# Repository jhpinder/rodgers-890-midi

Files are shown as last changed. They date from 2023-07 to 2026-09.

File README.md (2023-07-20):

# Rodgers 890 Westminster MIDI Project

## Overview 

When installed and used correctly, this project:

- allows the 890 console to be used as a MIDI controller/receiver
- prevents the 890 from emitting any original analog sounds
- is non-destructive to the original analog tone generation
- gives the option to revert back to the original 890 analog tone generation

## Theory

The 890 reads in keyboards/pistons/stops using 4021 shift registers.
There are five data input chains:
- swell
- great
- pedal
- choir
- drawknobs/tablets

The 890 sets lamp outputs using 4094 shift registers into 2804 transistors.
There are six output chains:
- pipe chest
- swell/choir
- great
- pedal
- stops
- lamps

We will be using all the input chains since we are using almost every input, but only the sixth output for lamps since we are only driving lamps.

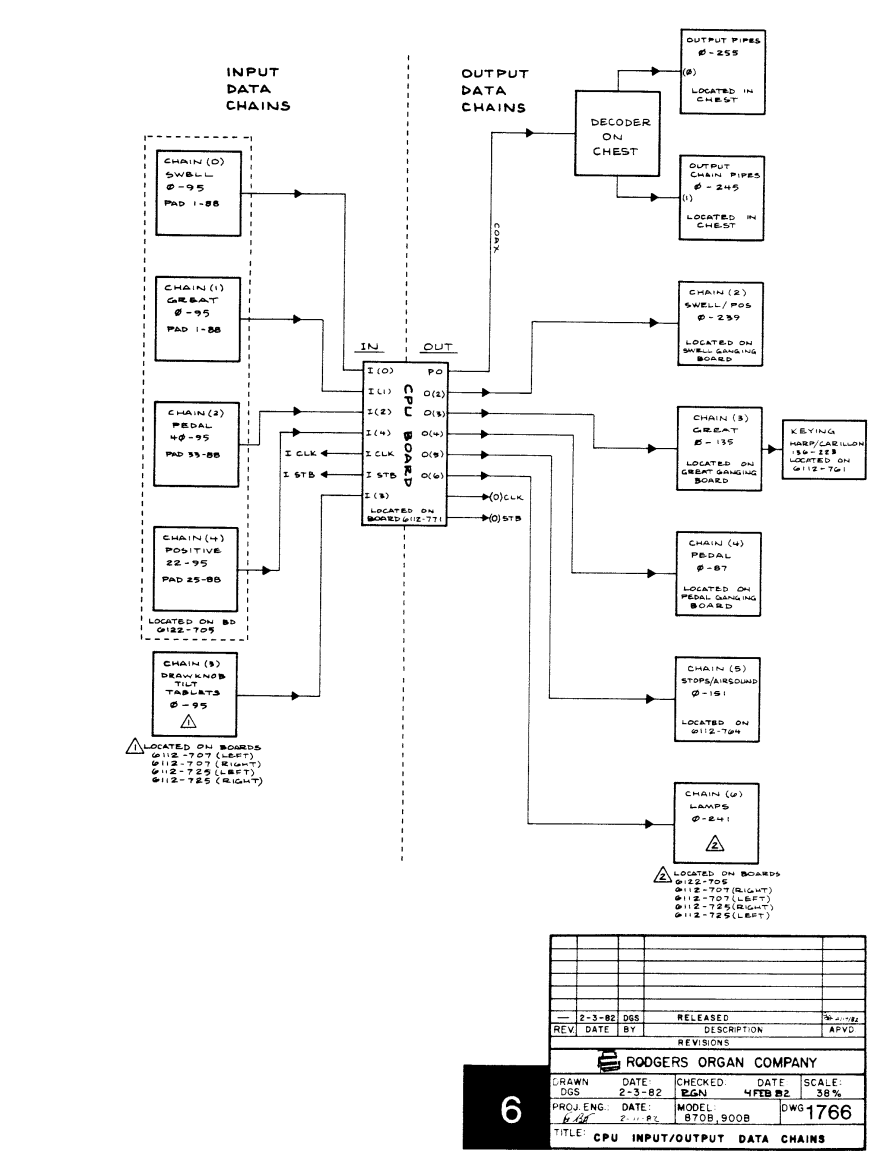
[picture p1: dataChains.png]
Data chains


---
### MIDI Latency

Every MIDI note command take approximately 1 millisecond to transmit.
We have over 90 lamps that can be changed at any time from the MIDI input.
This means if there are 50 lamp changes, it will take at least 50ms before the processor empties out the MIDI receive queue.
The acceptable time between note refreshing is 10ms.
If the organist is playing notes constantly and presses a piston that changes more than 10 lamps, there will theoretically be a delay before the next note refresh.

There are several solutions to this issue.

### *Solution 1: Hardware separation of keyboards and stops*

We can use one processor and MIDI port to process all the keyboards and their corresponding pistons and another processor and MIDI port to handle all the stops and lamps.
USB-MIDI interfaces sometimes feature multiple MIDI ports which are completely independent of each other.
This would allow one processor to dedicate its MIDI port to sending keyboard/piston note commands with no connection to the stops/lamps.
The other processor would be able to spend as much time as needed to receive MIDI notes and update lamps.

### *Solution 2 (**Current**): MIDI receive processing limits*

During each loop, we check if `MIDI.read()` is true (if there is an incoming message).
We continue to process MIDI messages in each loop until the incoming queue is empty.
However, if we receive more than 10 note commands at once, that breaks the limit of 10ms.
Before each time we check for an incoming message, we check to see if more than 10ms has elapsed since the last keyboard scan.
We do not update the lamps until the entire message queue has been emptied so as not to possibly create a ripple effect.
This complicates the code a little bit but allows the entire organ to run off of one MIDI port.
The logic for determining if more than the allowed amount of time has passed since the last keyboard read can be bypassed by connecting pin 3 to ground. For this to take effect, the arduino must be reset.

---
### Drawknobs and Tilt Tabs

Each drawknob and tilt tab has a lamp, an "on" contact, and an "off" contact.
When you turn the stop on, you pull the drawknob and release.
The lamp turns on and the drawknob moves back to its default center position.
The same goes for pushing the stop to turn it off.
The act of pushing or pulling a stop physically changes the state of the 2804 transistor and also changes the state of the corresponding 4021 shift register.
This means that there is a possibility of echoing a MIDI note on or note off command coming from the organ software.

To solve this issue, when receiving MIDI note commands, we `or` the "previous state" word with any reveiced MIDI note command. When scanning for changes on the next loop, those changes that are now read in do not trigger new MIDI note commands to be sent back to the organ software.

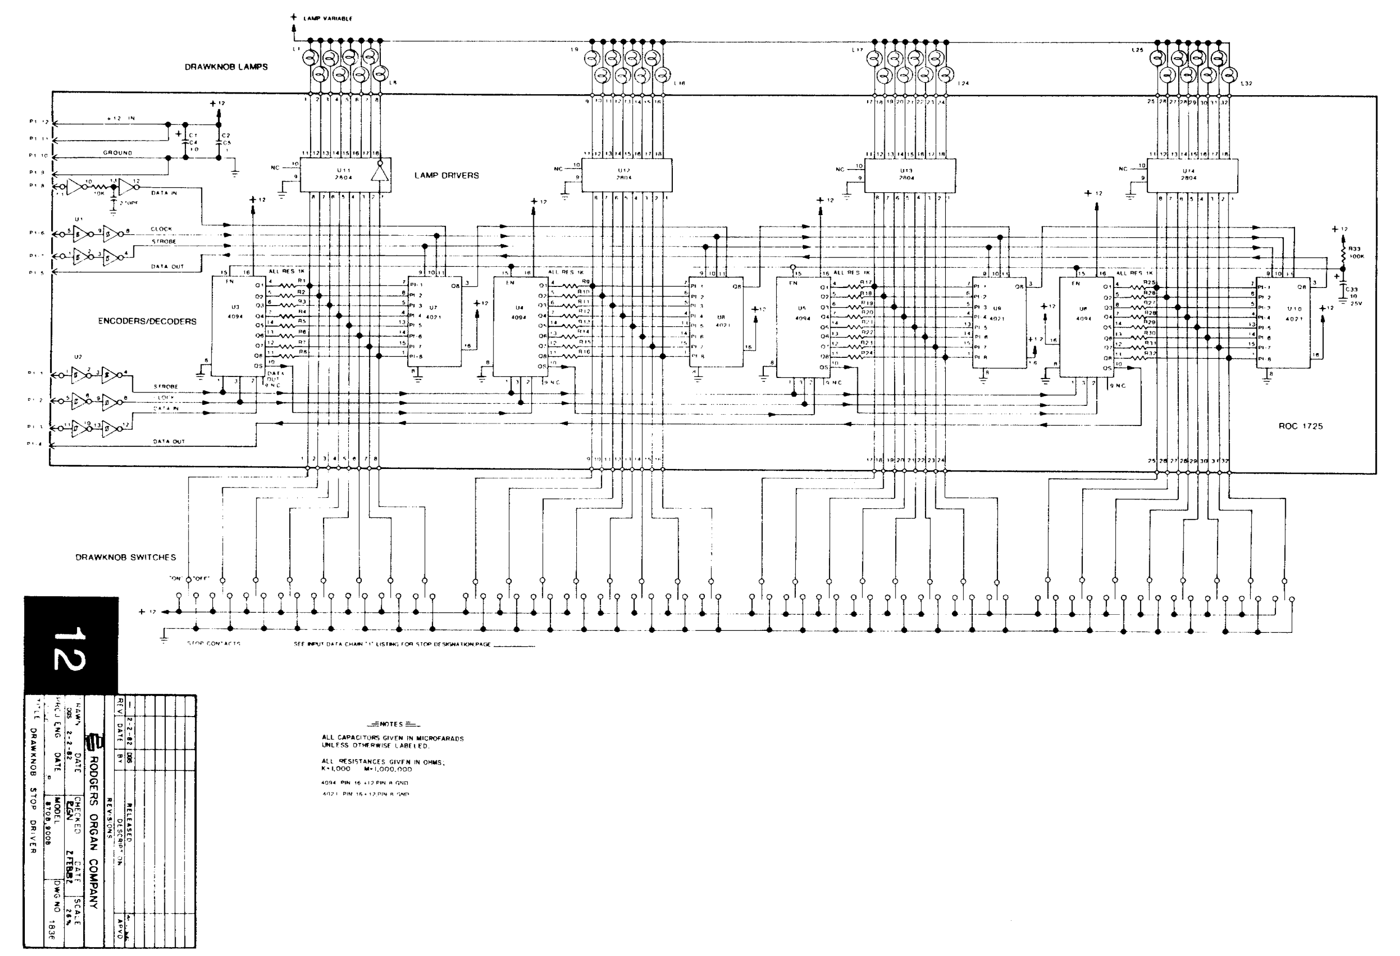
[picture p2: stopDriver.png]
Stop driver


---
### I/O Chain <-> MIDI

There are 5 input chains and one output chain that interface with MIDI. Four of the input chains contain a keyboard but they do not start at the 36th position, rather the 33rd for manuals and 65th for pedals.
If we output the raw chain position to MIDI, there will be a transposition required by the organ software.
Instead, we have opted to shift the positions of the input chain before we send out the MIDI note events.
This also means that the pistons associated with each keyboard are shifted as well.
To further complicate the matter, the lamps associated with each piston are not lined up 1:1 in an output chain with each input piston.
Instead, the piston lamps are added on to the end of the drawknob lamp output chain.

We have developed two functions that interface between the I/O chains and MIDI events.
The function `chainToMidi()` accepts the input chain number and bit address, and returns the corresponding MIDI channel and note number.
The function `midiToChain()` accepts a MIDI channel and note, and returns the corresponding output chain number and bit address.

This allows us to convert from the I/O chain to MIDI note/channel and back very quickly without having to implement a lookup table.

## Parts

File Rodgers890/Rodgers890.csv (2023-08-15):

# | Reference | Qty | Value | Footprint | DNP
1 | A1 | 1 | Arduino_Leonardo | Module:Arduino_UNO_R3
2 | C1, C2, C3, C4, C6, C8, C9 | 7 | 0.1uF | Capacitor_SMD:C_0603_1608Metric_Pad1.08x0.95mm_HandSolder
3 | C5 | 1 | 100uF | Capacitor_THT:CP_Radial_D12.5mm_P7.50mm
4 | C7 | 1 | 10uF | Capacitor_SMD:C_1206_3216Metric_Pad1.33x1.80mm_HandSolder
5 | J1 | 1 | Conn_01x30_Pin | Connector_Card:CardEdge_125_30_of_50
6 | J2 | 1 | Conn_01x02_Pin | Connector_PinHeader_2.54mm:PinHeader_1x02_P2.54mm_Vertical
7 | Q1, Q3 | 2 | BC817 | Package_TO_SOT_SMD:SOT-23
8 | Q2, Q4 | 2 | BC807 | Package_TO_SOT_SMD:SOT-23
9 | R1, R13, R17, R18, R19 | 5 | 2.2K | Resistor_SMD:R_0603_1608Metric_Pad0.98x0.95mm_HandSolder
10 | R2, R3, R4, R5, R6, R24 | 6 | 6.8K | Resistor_SMD:R_0603_1608Metric_Pad0.98x0.95mm_HandSolder
11 | R7, R8, R9, R10, R14, R25 | 6 | 4.7K | Resistor_SMD:R_0603_1608Metric_Pad0.98x0.95mm_HandSolder
12 | R11, R12, R15, R16 | 4 | 10 | Resistor_SMD:R_0603_1608Metric_Pad0.98x0.95mm_HandSolder
13 | R20, R21, R22, R23 | 4 | 1K | Resistor_SMD:R_0603_1608Metric_Pad0.98x0.95mm_HandSolder
14 | TP1, TP21, TP22, TP23, TP24, TP25, TP26, TP27, TP28, TP29, TP30, TP31, TP32, TP33, TP34, TP35, TP36, TP37, TP38, TP39, TP40, TP41, TP42, TP43, TP44, TP45, TP46, TP48, TP50 | 29 | TestPoint | TestPoint:TestPoint_THTPad_2.0x2.0mm_Drill1.0mm
15 | U1 | 1 | 7417 | Package_SO:SOIC-14_3.9x8.7mm_P1.27mm
16 | U2 | 1 | 4050 | Package_SO:SOIC-16_3.9x9.9mm_P1.27mm

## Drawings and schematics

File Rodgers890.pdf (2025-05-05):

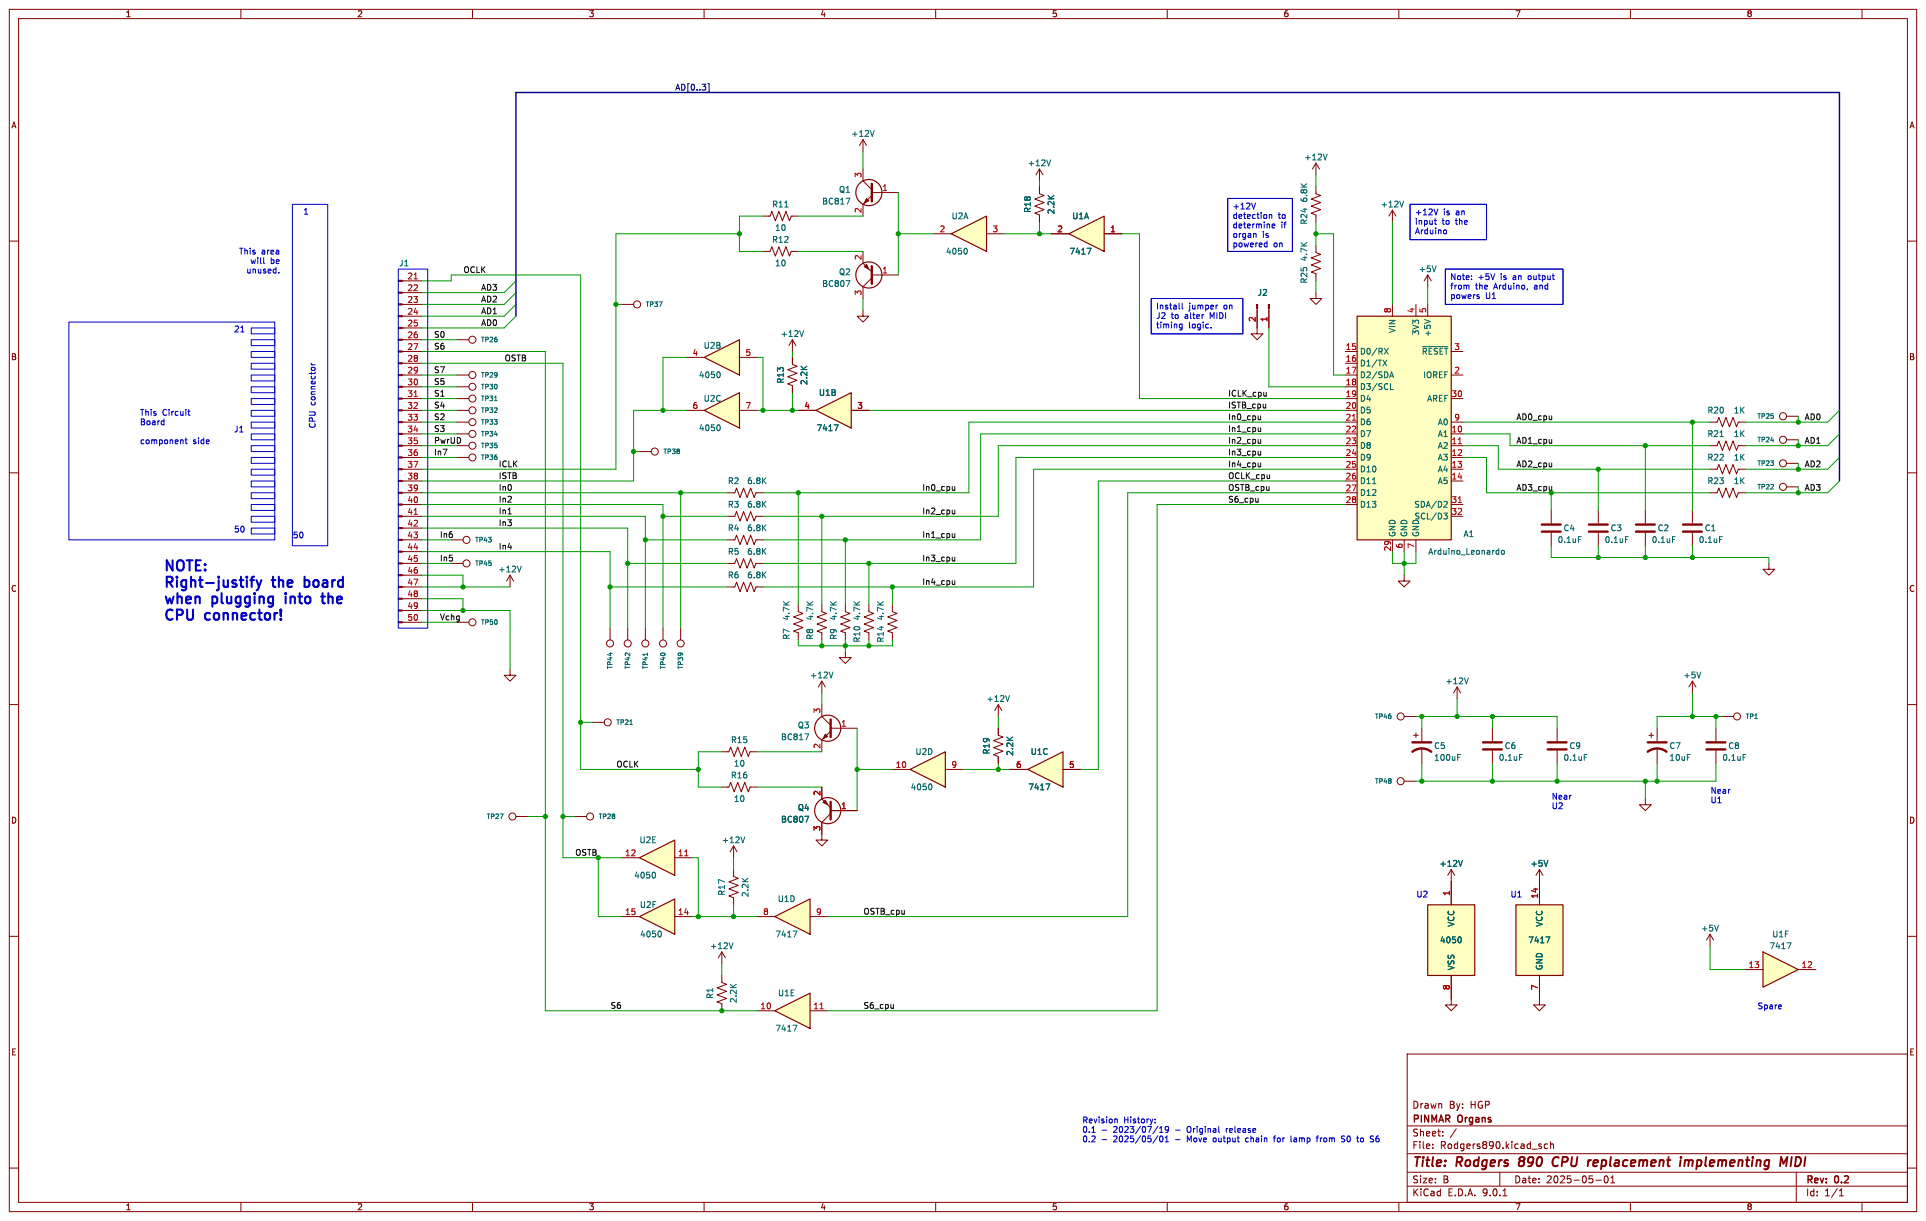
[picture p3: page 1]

input to the Arduino This Circuit Board

from the Arduino, and

IOREF 2 AREF 30 A0 9 A1 10 A2 11 A3 12 A4 13 A5 14 SDA/D2 31 SCL/D3 32 A1 Arduino_Leonardo TP40

when plugging into the
CPU connector!

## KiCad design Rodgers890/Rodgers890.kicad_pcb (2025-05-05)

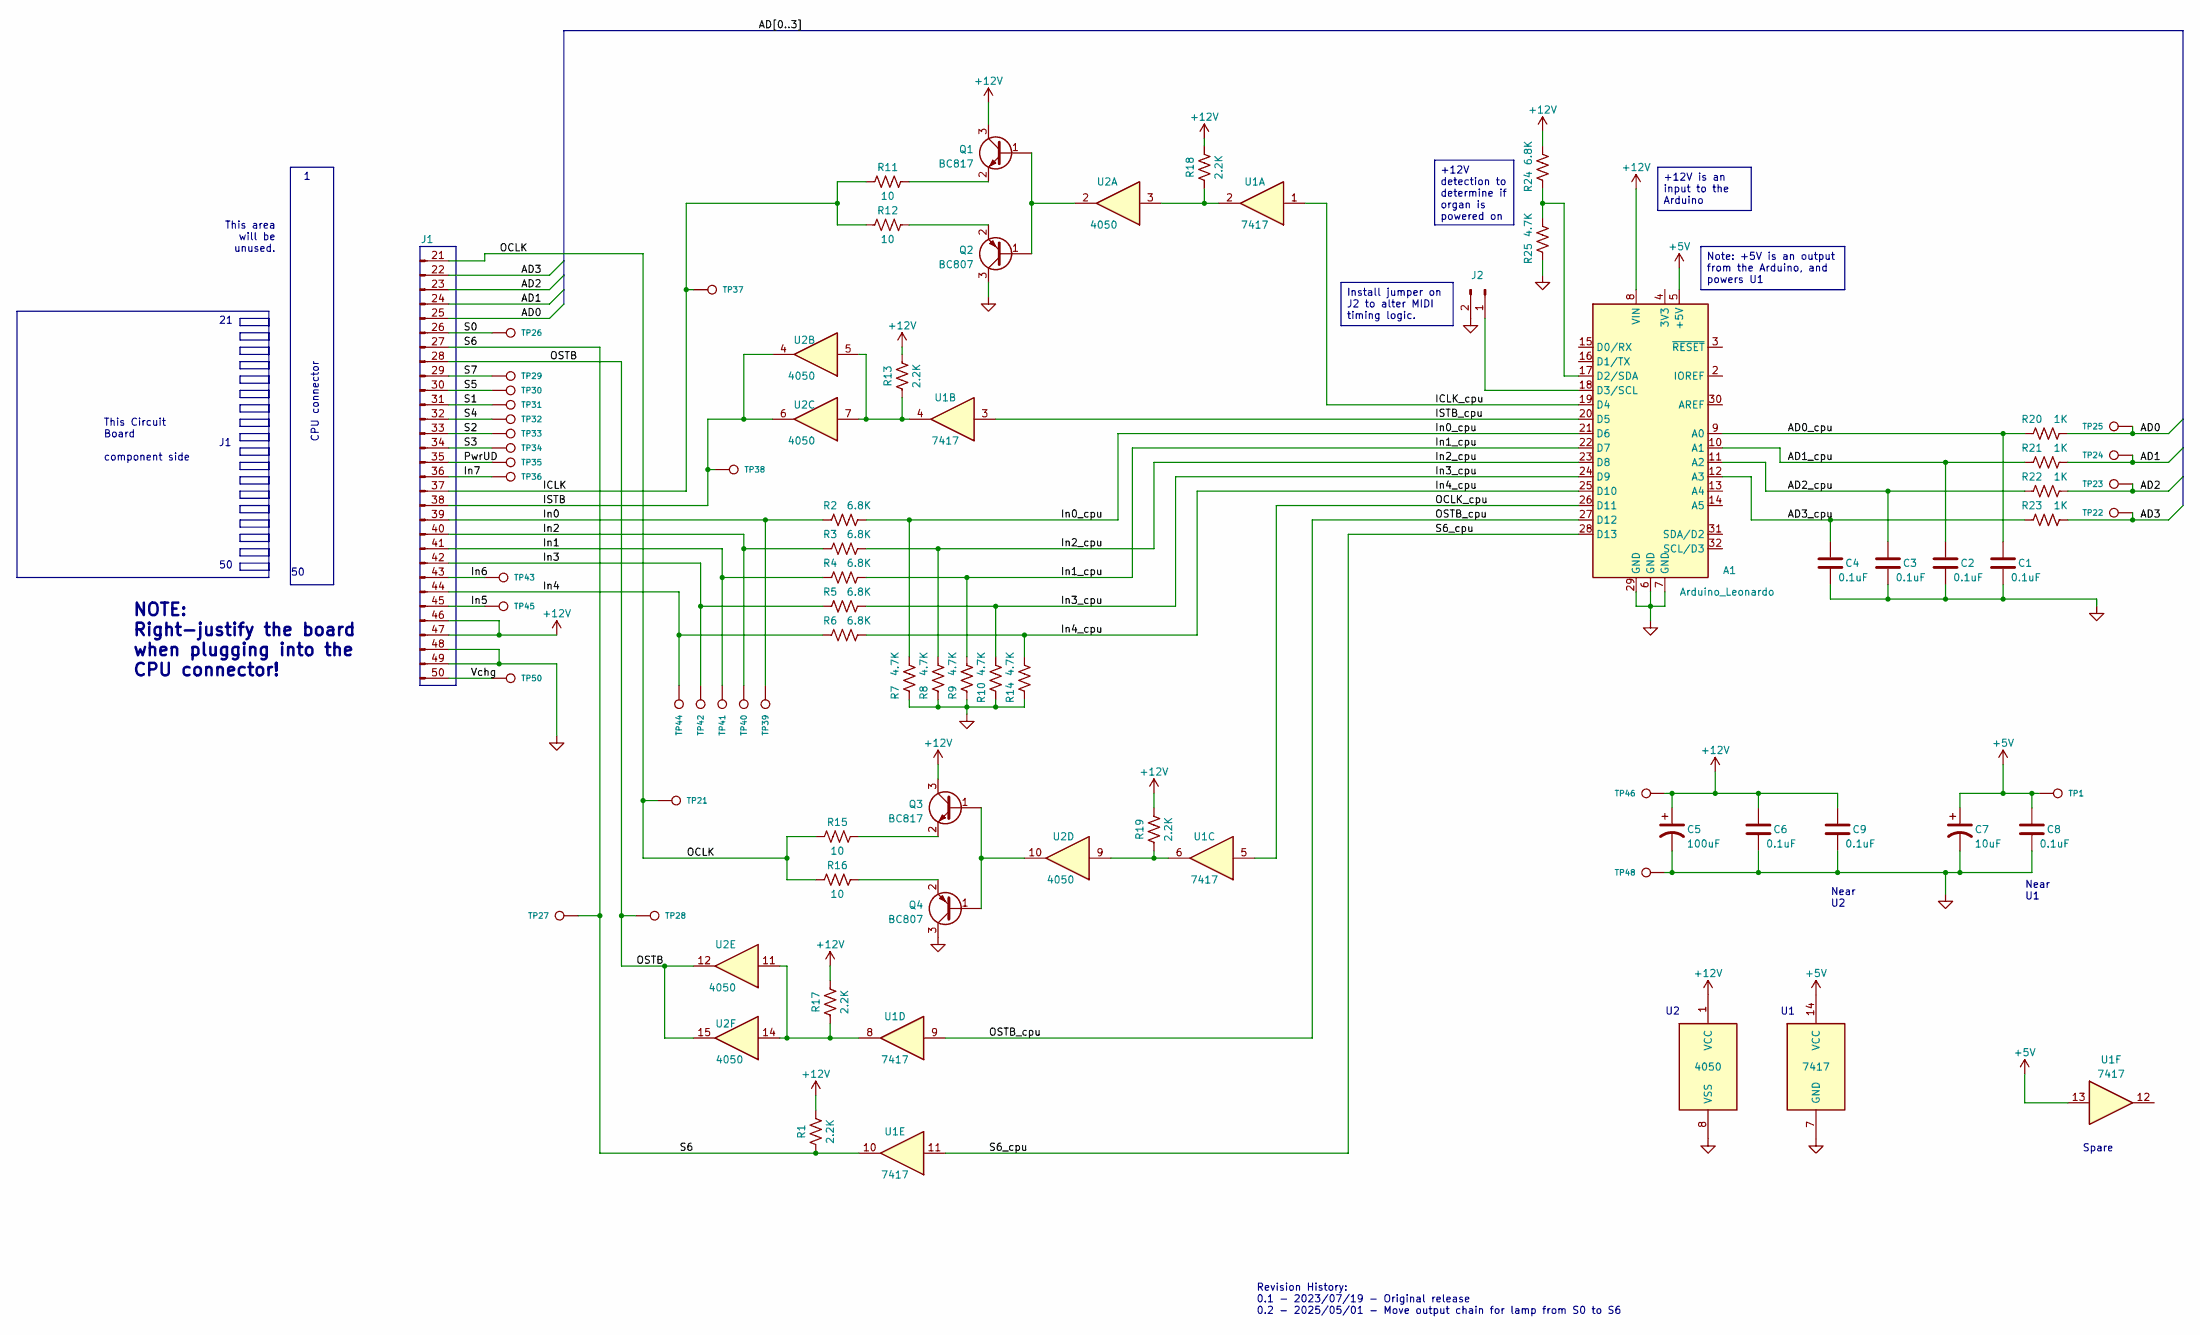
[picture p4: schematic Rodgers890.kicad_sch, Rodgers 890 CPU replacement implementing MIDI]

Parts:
A1: Arduino_Leonardo; Arduino_UNO_R3
C1, C2, C3, C4, C6, C8, C9: 0.1uF; C_0603_1608Metric_Pad1.08x0.95mm_HandSolder
C5: 100uF; CP_Radial_D12.5mm_P7.50mm
C7: 10uF; C_1206_3216Metric_Pad1.33x1.80mm_HandSolder
J1: Conn_01x30_Pin; CardEdge_125_30_of_50
J2: Conn_01x02_Pin; PinHeader_1x02_P2.54mm_Vertical
Q1, Q3: BC817; SOT-23
Q2, Q4: BC807; SOT-23
R1, R13, R17, R18, R19: 2.2K; R_0603_1608Metric_Pad0.98x0.95mm_HandSolder
R2, R3, R4, R5, R6, R24: 6.8K; R_0603_1608Metric_Pad0.98x0.95mm_HandSolder
R7, R8, R9, R10, R14, R25: 4.7K; R_0603_1608Metric_Pad0.98x0.95mm_HandSolder
R11, R12, R15, R16: 10; R_0603_1608Metric_Pad0.98x0.95mm_HandSolder
R20, R21, R22, R23: 1K; R_0603_1608Metric_Pad0.98x0.95mm_HandSolder
TP1, TP21, TP22, TP23, TP24, TP25, TP26, TP27, TP28, TP29, TP30, TP31, TP32, TP33, TP34, TP35, TP36, TP37, TP38, TP39, TP40, TP41, TP42, TP43, TP44, TP45, TP46, TP48, TP50: TestPoint; TestPoint_THTPad_2.0x2.0mm_Drill1.0mm
U1: 7417; SOIC-14_3.9x8.7mm_P1.27mm
U2: 4050; SOIC-16_3.9x9.9mm_P1.27mm

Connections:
+5V: A1.5 (+5V), C7.1, C8.1, TP1.1, U1.13, U1.14 (VCC)
+12V: A1.8 (VIN), C5.1, C6.1, C9.1, J1.46, J1.47, Q1.3 (C), Q3.3 (C), R1.2, R13.2, R17.2, R18.2, R19.2, R24.2, TP46.1, U2.1 (VCC)
/AD0: J1.25, R20.2, TP25.1
/AD0_cpu: A1.9 (A0), C1.1, R20.1
/AD1: J1.24, R21.2, TP24.1
/AD1_cpu: A1.10 (A1), C2.1, R21.1
/AD2: J1.23, R22.2, TP23.1
/AD2_cpu: A1.11 (A2), C3.1, R22.1
/AD3: J1.22, R23.2, TP22.1
/AD3_cpu: A1.12 (A3), C4.1, R23.1
/ICLK: J1.37, R11.1, R12.1, TP37.1
/ICLK_cpu: A1.19 (D4), U1.1
/ISTB: J1.38, TP38.1, U2.4, U2.6
/ISTB_cpu: A1.20 (D5), U1.3
/In0: J1.39, R2.1, TP39.1
/In0_cpu: A1.21 (D6), R2.2, R7.2
/In1: J1.41, R4.1, TP41.1
/In1_cpu: A1.22 (D7), R4.2, R9.2
/In2: J1.40, R3.1, TP40.1
/In2_cpu: A1.23 (D8), R3.2, R8.2
/In3: J1.42, R5.1, TP42.1
/In3_cpu: A1.24 (D9), R5.2, R10.2
/In4: J1.44, R6.1, TP44.1
/In4_cpu: A1.25 (D10), R6.2, R14.2
/In5: J1.45, TP45.1
/In6: J1.43, TP43.1
/In7: J1.36, TP36.1
/OCLK: J1.21, R15.1, R16.1, TP21.1
/OCLK_cpu: A1.26 (D11), U1.5
/OSTB: J1.28, TP28.1, U2.12, U2.15
/OSTB_cpu: A1.27 (D12), U1.9
/PwrUD: J1.35, TP35.1
/S0: J1.26, TP26.1
/S1: J1.31, TP31.1
/S2: J1.33, TP33.1
/S3: J1.34, TP34.1
/S4: J1.32, TP32.1
/S5: J1.30, TP30.1
/S6: J1.27, R1.1, TP27.1, U1.10
/S6_cpu: A1.28 (D13), U1.11
/S7: J1.29, TP29.1
/Vchg: J1.50, TP50.1
GND: A1.6 (GND), A1.7 (GND), A1.29 (GND), C1.2, C2.2, C3.2, C4.2, C5.2, C6.2, C7.2, C8.2, C9.2, J1.48, J1.49, J2.2, Q2.3 (C), Q4.3 (C), R7.1, R8.1, R9.1, R10.1, R14.1, R25.1, TP48.1, U1.7 (GND), U2.8 (VSS)
unnamed: A1.17 (D2/SDA), R24.1, R25.2
unnamed: A1.18 (D3/SCL), J2.1
unnamed: Q1.1 (B), Q2.1 (B), U2.2
unnamed: Q1.2 (E), R11.2
unnamed: Q2.2 (E), R12.2
unnamed: Q3.1 (B), Q4.1 (B), U2.10
unnamed: Q3.2 (E), R15.2
unnamed: Q4.2 (E), R16.2
unnamed: R13.1, U1.4, U2.5, U2.7
unnamed: R17.1, U1.8, U2.11, U2.14
unnamed: R18.1, U1.2, U2.3
unnamed: R19.1, U1.6, U2.9

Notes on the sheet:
Near U2
This Circuit Board component side
Spare
This area will be unused.
NOTE: Right-justify the board when plugging into the CPU connector!
Near U1
CPU connector
Revision History: 0.1 - 2023/07/19 - Original release 0.2 - 2025/05/01 - Move output chain for lamp from S0 to S6
+12V detection to determine if organ is powered on
Install jumper on J2 to alter MIDI timing logic.
Note: +5V is an output from the Arduino, and powers U1
+12V is an input to the Arduino

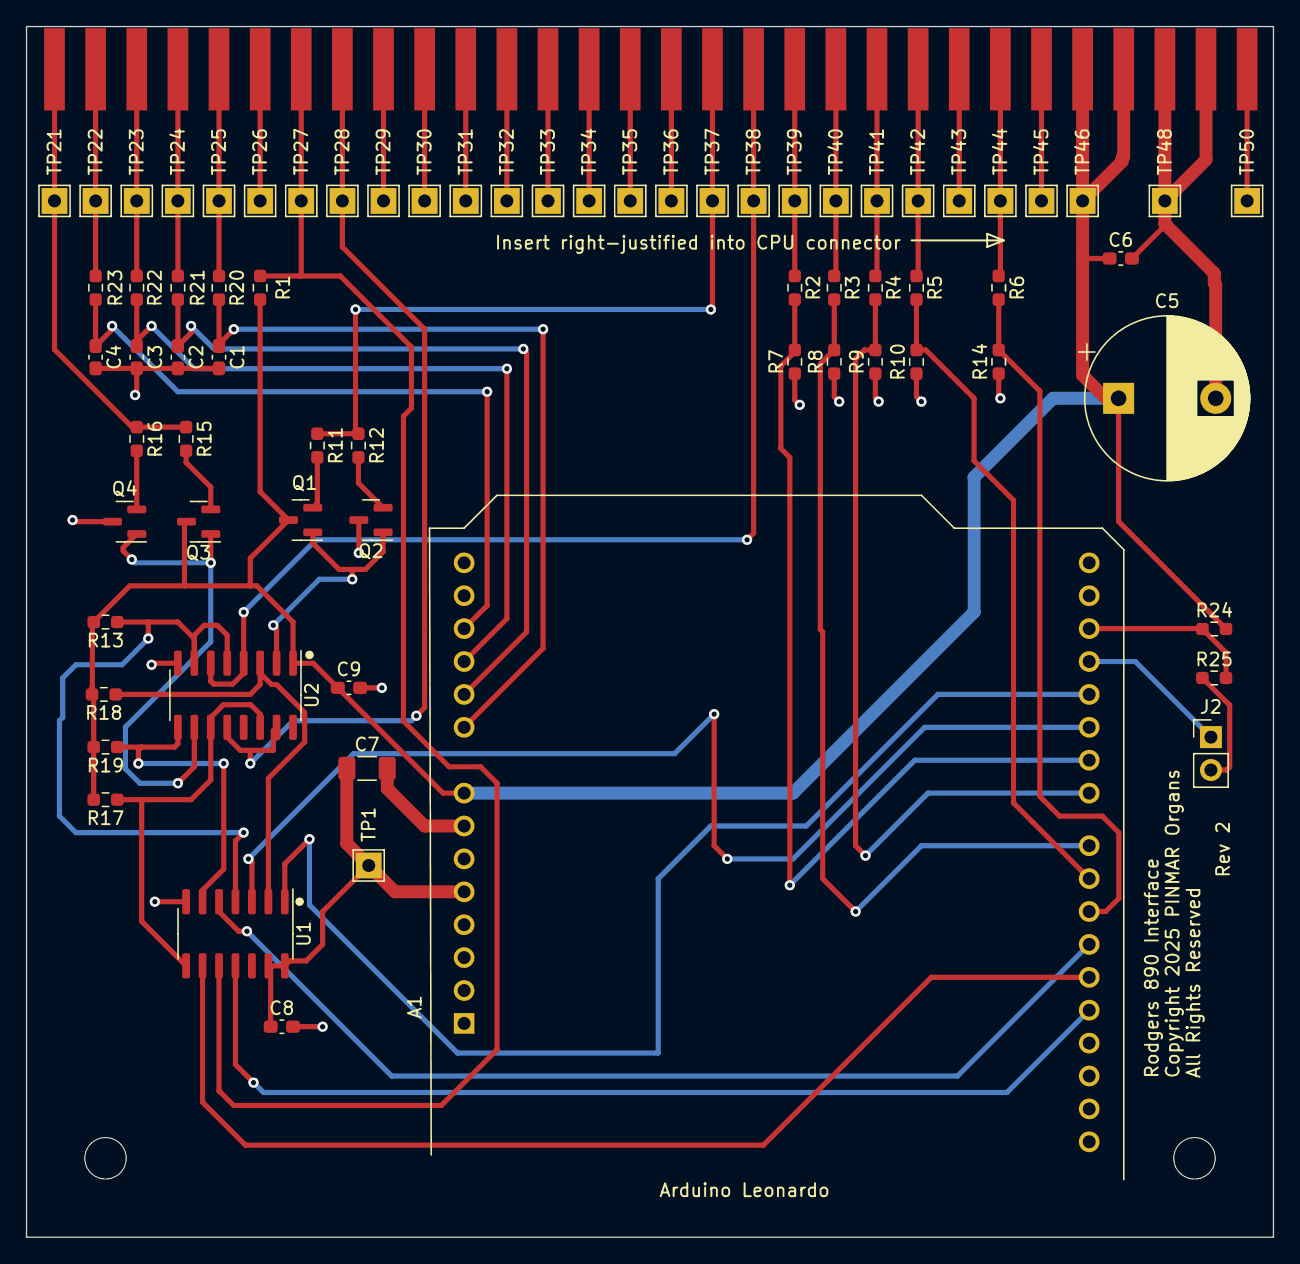
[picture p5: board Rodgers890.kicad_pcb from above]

Board: 2 copper layers, 96.3 x 93.5 mm, 72 parts (0 on the bottom side), 55 nets.

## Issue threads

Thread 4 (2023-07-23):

Wrong output chain used

pinderh2, 2023-07-23:
Hardware issue: Output chain for lamps is connected to S0, instead of S6.
Work-around is to cut one trace and add one jumper to PCB.

pinderh2, 2025-05-01:
Fix made in Schematic and PCB.
Schematic updated to Rev 0.2
PCB updated to Rev 2
There are no plans to order PCBs with these changes.

Closed 2025-05-01.

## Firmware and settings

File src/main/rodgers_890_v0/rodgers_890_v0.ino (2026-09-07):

#include <MIDIUSB.h>

#define POWER_DETECT 2
#define RECEIVE_MIDI_LIMIT_PIN 3

#define ICLK 4
#define ISTB 5
#define I0 6  // swell
#define I1 7  // great
#define I2 8  // pedal
#define I3 9  // drawknobs
#define I4 10 // choir

#define OCLK 11
#define OSTB 12
#define O6 13

#define ISTB_DELAY 1 // microseconds
#define ICLK_DELAY 1

#define OSTB_DELAY 1
#define OCLK_DELAY 1

#define INPUT_CHAIN_SIZE 96

#define NOTE_ON_VELOCITY 64
#define NOTE_OFF_VELOCITY 64

#define NOTE_ON 0x90
#define NOTE_OFF 0x80

#define SWELL_CHANNEL 0
#define GREAT_CHANNEL 1
#define PEDAL_CHANNEL 2
#define STOP_TAB_CHANNEL 3
#define CHOIR_CHANNEL 4

#define MIDI_CC_NUM 7
#define ANALOG_DIFF 10

#define MIDI_ADDR_NONE 0xFF      // midiToChain() "no mapping" sentinel
#define MIDI_IDLE_MS 5           // ms of MIDI-in silence before strobing lamps
#define LAMP_STROBE_INTERVAL 250 // ms: force a lamp re-strobe even mid-burst

byte currentInputChain[5][96];
byte previousInputChain[5][96];
// 0 = swell, 1 = great, 2 = pedal, 3 = stops, 4 = choir

byte lampChainState[152];

int previousAnalogInputs[4];
int currentAnalogInputs[4];

unsigned long prevMillis = 0;       // last time an inbound MIDI packet was seen
unsigned long lastLampStrobeMs = 0; // last time updateLamps() strobed the chain

struct midiAddr
{
  byte channel;
  byte note;
};

struct chainAddr
{
  byte number;
  byte value;
};

void pumpMidi();
void handleMidiPacket(midiEventPacket_t rx);

void setup()
{
  pinMode(ICLK, OUTPUT);
  pinMode(ISTB, OUTPUT);
  pinMode(I0, INPUT);
  pinMode(I1, INPUT);
  pinMode(I2, INPUT);
  pinMode(I3, INPUT);
  pinMode(I4, INPUT);
  pinMode(OCLK, OUTPUT);
  pinMode(OSTB, OUTPUT);
  pinMode(O6, OUTPUT);
  pinMode(RECEIVE_MIDI_LIMIT_PIN, INPUT_PULLUP);
  pinMode(POWER_DETECT, INPUT);

  //  Serial.begin(312500);
}

void loop()
{
  shiftInputs();
  scanAnalogInputs();

  pumpMidi();

  if (millis() - prevMillis > MIDI_IDLE_MS ||
      millis() - lastLampStrobeMs > LAMP_STROBE_INTERVAL)
  {
    updateLamps();
  }

  handleInputChanges();
  MidiUSB.flush();
}

// Drain everything the USB-MIDI OUT endpoint currently holds. Called not only
// once per loop but repeatedly from inside shiftInputs()/scanAnalogInputs()/
// updateLamps() so the 32U4's 64-byte (16-event) MIDI FIFO never overflows
// during a large inbound burst (e.g. Cancel clearing many stops at once). An
// overflow makes the host retry back-to-back, which a marginal USB clock/analog
// path can turn into dropped Note Offs -> stops that don't cancel.
void pumpMidi()
{
  midiEventPacket_t rx;
  while ((rx = MidiUSB.read()).header != 0)
  {
    handleMidiPacket(rx);
    prevMillis = millis();
  }
}

void updateLamps()
{
  // Shift out from a snapshot: the pumpMidi() calls below write lampChainState[],
  // so working from a copy keeps this strobe self-consistent; any change that
  // lands mid-strobe is picked up on the next strobe.
  byte lamps[sizeof(lampChainState)];
  memcpy(lamps, lampChainState, sizeof(lampChainState));

  for (int i = sizeof(lamps) - 1; i >= 0; i--)
  {
    // output chain
    digitalWrite(O6, lamps[i]);
    // clock
    delayMicroseconds(OCLK_DELAY);
    digitalWrite(OCLK, HIGH);
    delayMicroseconds(OCLK_DELAY);
    digitalWrite(OCLK, LOW);
    delayMicroseconds(OCLK_DELAY);

    if ((i & 0x0F) == 0)
    {
      pumpMidi();
    }
  }
  // strobe
  digitalWrite(OSTB, HIGH);
  delayMicroseconds(OSTB_DELAY);
  digitalWrite(OSTB, LOW);

  lastLampStrobeMs = millis();
}

void handleInputChanges()
{
  // switches
  for (int input_number = 0; input_number < INPUT_CHAIN_SIZE; input_number++)
  {
    for (int chain = 0; chain < 5; chain++)
    {
      if (currentInputChain[chain][input_number] != previousInputChain[chain][input_number])
      {
        if (chain == SWELL_CHANNEL && input_number == 95 && currentInputChain[chain][input_number])
        {
          if (lampChainState[141])
          {
            noteOn(SWELL_CHANNEL, 127, 64);
          }
          else
          {
            noteOn(SWELL_CHANNEL, 99, 64);
          }
        }
        else
        {
          // input is different than last scan
          midiAddr midiToSend = chainToMidi({chain, input_number});
          if (currentInputChain[chain][input_number])
          {
            // input turned on, send midi note on
            noteOn(midiToSend.channel, midiToSend.note, NOTE_ON_VELOCITY);
          }
          else
          {
            // input turned off, send midi note off
            noteOff(midiToSend.channel, midiToSend.note, NOTE_OFF_VELOCITY);
          }
        }
      }
      previousInputChain[chain][input_number] = currentInputChain[chain][input_number];
    }
  }
  // analog inputs
  for (int i = 0; i < 4; i++)
  {
    int diff = currentAnalogInputs[i] - previousAnalogInputs[i];
    if (diff > ANALOG_DIFF || diff < -ANALOG_DIFF)
    {
      // map 0-1023 to 0-127
      sendCC(i, MIDI_CC_NUM, map(currentAnalogInputs[i], 0, 1023, 0, 127));
      previousAnalogInputs[i] = currentAnalogInputs[i];
    }
  }
}

void shiftInputs()
{
  // pulse strobe to store data into registers
  digitalWrite(ISTB, HIGH);
  delayMicroseconds(ISTB_DELAY);
  digitalWrite(ISTB, LOW);
  delayMicroseconds(ICLK_DELAY);

  for (int i = INPUT_CHAIN_SIZE - 1; i >= 0; i--)
  {
    // I0
    currentInputChain[0][i] = digitalRead(I0);
    // I1
    currentInputChain[1][i] = digitalRead(I1);
    // I2
    currentInputChain[2][i] = digitalRead(I2);
    // I3
    currentInputChain[3][i] = digitalRead(I3);
    // I4
    currentInputChain[4][i] = digitalRead(I4);

    // clock
    digitalWrite(ICLK, HIGH);
    delayMicroseconds(ICLK_DELAY);
    digitalWrite(ICLK, LOW);
    delayMicroseconds(ICLK_DELAY);

    // Keep servicing USB-MIDI mid-scan so an inbound burst can't overflow the
    // endpoint while this ~3 ms loop runs.
    if ((i & 0x07) == 0)
    {
      pumpMidi();
    }
  }
}

// Apply one inbound USB-MIDI packet to the lamp state. Ignores anything that is
// not a Note On / Note Off, and refuses to act when midiToChain() can't map the
// channel/note (it returns MIDI_ADDR_NONE) or maps out of range -- both of those
// previously caused out-of-bounds writes past lampChainState[] that could
// silently corrupt prevMillis and the analog input state.
//
// This ONLY writes lampChainState[]. It must not write previousInputChain[]:
// Hauptwerk owns stop state, the console just mirrors it, and the stop switches
// latch (the 4021 bit stays set from "pull" until "push"). So:
//   - a physical pull already lands current==previous==on -> no echo to suppress;
//   - a piston/preset never moves currentInputChain[] -> no echo to suppress;
//   - forcing previousInputChain[] to the commanded value here was what made
//     Cancel fight itself: midiToChain() returns a LAMP index (note + 8) for the
//     stop-tab channel, so "Note Off ch3 N" was zeroing previousInputChain[3]
//     [N+8]; on the next scan a still-latched knob at input N+8 read as a 0->1
//     change and Leonardo re-sent "Note On ch3 N+8", turning that stop back on.
//     Dense registrations have many such N / N+8 pairs, which is why a big Cancel
//     left stops set and a second press was needed.
void handleMidiPacket(midiEventPacket_t rx)
{
  byte status = rx.byte1 & 0xF0;
  if (status != NOTE_ON && status != NOTE_OFF)
  {
    return;
  }

  // Note On with velocity 0 is a Note Off.
  bool stopOn = (status == NOTE_ON) && (rx.byte3 != 0);

  chainAddr chainToChange = midiToChain({rx.byte1 & 0x0F, rx.byte2});
  if (chainToChange.number == MIDI_ADDR_NONE ||
      chainToChange.value >= sizeof(lampChainState))
  {
    return;
  }

  lampChainState[chainToChange.value] = stopOn;
}

void noteOn(byte channel, byte pitch, byte velocity)
{
  midiEventPacket_t noteOn = {0x09, 0x90 | channel, pitch, velocity};
  MidiUSB.sendMIDI(noteOn);
}

void noteOff(byte channel, byte pitch, byte velocity)
{
  midiEventPacket_t noteOff = {0x08, 0x80 | channel, pitch, velocity};
  MidiUSB.sendMIDI(noteOff);
}

void sendCC(byte channel, byte number, byte value)
{
  MidiUSB.sendMIDI({0x0B, 0xB0 | channel, number, value});
}

midiAddr chainToMidi(chainAddr chain)
{
  midiAddr result = {MIDI_ADDR_NONE, MIDI_ADDR_NONE};

  if (chain.number == SWELL_CHANNEL || chain.number == GREAT_CHANNEL || chain.number == CHOIR_CHANNEL)
  {
    result.channel = chain.number;
    result.note = chain.value + 4;
  }
  else if (chain.number == PEDAL_CHANNEL)
  {
    if (chain.value == 47)
    {
      result.channel = GREAT_CHANNEL;
      result.note = 19;
    }
    else
    {
      result.channel = chain.number;
      result.note = chain.value - 28;
    }
  }
  else if (chain.number == STOP_TAB_CHANNEL)
  {
    result.note = chain.value;
    result.channel = chain.number;
  }

  return result;
}

chainAddr midiToChain(midiAddr midiEvent)
{
  chainAddr result = {MIDI_ADDR_NONE, MIDI_ADDR_NONE};

  if (midiEvent.channel == SWELL_CHANNEL || midiEvent.channel == GREAT_CHANNEL || midiEvent.channel == CHOIR_CHANNEL)
  {
    result.number = STOP_TAB_CHANNEL;
    switch (midiEvent.channel)
    {
    case SWELL_CHANNEL:
      if (midiEvent.note >= 19 && midiEvent.note <= 26)
      {
        result.value = midiEvent.note + 85;
      }
      else if (midiEvent.note >= 28 && midiEvent.note <= 30)
      {
        result.value = midiEvent.note + 83;
      }
      else if (midiEvent.note == 99)
      {
        result.value = 141;
      }
      break;
    case GREAT_CHANNEL:
      if (midiEvent.note >= 11 && midiEvent.note <= 15)
      {
        result.value = midiEvent.note + 103;
      }
      else if (midiEvent.note >= 19 && midiEvent.note <= 24)
      {
        result.value = midiEvent.note + 101;
      }
      else if (midiEvent.note >= 27 && midiEvent.note <= 31)
      {
        result.value = midiEvent.note + 100;
      }
      break;
    case CHOIR_CHANNEL:
      if (midiEvent.note >= 13 && midiEvent.note <= 14)
      {
        result.value = midiEvent.note + 119;
      }
      else if (midiEvent.note >= 18 && midiEvent.note <= 23)
      {
        result.value = midiEvent.note + 116;
      }
      else if (midiEvent.note >= 24 && midiEvent.note <= 27)
      {
        result.value = midiEvent.note + 119;
      }
      else if (midiEvent.note >= 29 && midiEvent.note <= 32)
      {
        result.value = midiEvent.note + 118;
      }
      break;
    default:
      break;
    }
  }
  else if (midiEvent.channel == STOP_TAB_CHANNEL)
  {
    result.value = midiEvent.note + 8;
    result.number = STOP_TAB_CHANNEL;
  }
  else if (midiEvent.channel == PEDAL_CHANNEL)
  {
    // No lamps on the pedal channel; leave result unmapped.
  }

  return result;
}

void scanAnalogInputs()
{
  currentAnalogInputs[0] = analogRead(A0);
  pumpMidi();
  currentAnalogInputs[1] = analogRead(A1);
  pumpMidi();
  currentAnalogInputs[2] = analogRead(A2);
  pumpMidi();
  currentAnalogInputs[3] = analogRead(A3);
  pumpMidi();
}

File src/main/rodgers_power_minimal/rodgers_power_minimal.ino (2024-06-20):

#include <Keyboard.h>
#define SWITCH_PIN 8
#define RELAY_PIN 4

boolean currentSwitchState;
boolean lastSwitchState;
boolean powerState;

void setup() {
  pinMode(SWITCH_PIN, INPUT_PULLUP);
  pinMode(RELAY_PIN, OUTPUT);
  currentSwitchState = readSwitchPin();
  lastSwitchState = currentSwitchState;
  powerState = false;
}

void loop() {
  if (currentSwitchState != lastSwitchState && currentSwitchState) {
    powerState ? turnOffRelay() : turnOnRelay();
  }
  lastSwitchState = currentSwitchState;
  delay(20);
  currentSwitchState = readSwitchPin();
}

void turnOnRelay() {
  powerState = true;
  digitalWrite(RELAY_PIN, HIGH);
  delay(2000);
}

void turnOffRelay() {
  powerState = false;
  digitalWrite(RELAY_PIN, LOW);
  delay(2000);
}

boolean readSwitchPin() {
  return !digitalRead(SWITCH_PIN);
}

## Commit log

2023-07-19 Create Rodgers890.pdf
    Schematic for CPU board replacement
2023-07-19 using midi-chain lookup functions
2023-07-20 Add J2 to select Midi mode to schematic. Update TP ref designators to match card edge pin numbers. Add inital proposed board layout for review.
2023-07-20 added power detect logic
2023-07-20 Add +12V detect and mounting holes
2023-07-22 Update schematic to match production PCB
2023-07-22 Remove prelim placement file (see full PCB design for those details)
2023-07-22 Add KiCad files representing the first PCB revision
    [Rodgers890.csv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]
2023-07-29 print received MIDI on stops
2023-08-15 gt/ped manual and toe pistons now send identical messages
2024-06-20 Add minimal power config
2025-05-01 Address Issue #4: Wrong output chain used, for schematic only. Revision marking on schematic becomes “Rev 0.2”
    [Rodgers890.kicad_sch]
2025-05-01 Address Issue #4: Wrong output chain used, for PCB. Revision marking on PCB is "Rev 2".
    [Rodgers890.kicad_pcb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]
2026-09-07 Fix large registration change issue
    [rodgers_890_v0.ino]
2026-10-21 firmware v0.2: drop spare ADC input, release build kit
    A3/AD3 is the shared-family Choir-expression channel — unwired on the
    890's three-pot pedal assembly it floats and spammed erratic CC7 on
    MIDI channel 4. ANALOG_INPUT_COUNT excludes it from scan and send.
    release/ carries the PlatformIO env used to build rodgers_890_v0.hex
    (incl. "Rodgers 890" USB product name) and the shipped hex.
    Generated with [Devin](https://devin.ai)
2026-10-21 firmware v0.3: real tutti note, pistons emit note-on only
    TUTTI_NOTE was a placeholder (30, borrowed from test data) that collided
    with General 8's lamp. Measured from the console: note 35 on the Great
    channel (91 23 40). The echo is now consumed before midiToChain -- the
    tutti piston has no lamp of its own; the 4 red indicator segments are
    its lamp.
    Pistons and toe studs are momentary: they now send Note On on press and
    nothing on release (manual bits 0-31, pedal bits 0-63). SET (ch1 note
    27) still reports release since it is held while capturing. Keys, pedal
    notes, and latching drawknob tabs keep both edges.
    Generated with [Devin](https://devin.ai)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

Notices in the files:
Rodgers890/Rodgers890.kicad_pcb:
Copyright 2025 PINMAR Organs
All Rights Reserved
